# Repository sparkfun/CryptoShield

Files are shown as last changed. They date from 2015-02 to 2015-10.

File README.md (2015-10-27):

SparkFun CryptoShield
=====================

SparkFun CryptoShield

[*SparkFun CryptoShield (DEV-13183)*](https://www.sparkfun.com/products/13183)

Repository Contents
-------------------

* **/Hardware** - Eagle design files (.brd, .sch)
* **/Production** - Production panel files (.brd)

Documentation
--------------

* **[Hookup Guide](https://learn.sparkfun.com/tutorials/crypto-shield-hookup-guide)** - Basic hookup guide for the CryptoShield.
* **[SparkFun Fritzing repo](https://github.com/sparkfun/Fritzing_Parts)** - Fritzing diagrams for SparkFun products.
* **[SparkFun 3D Model repo](https://github.com/sparkfun/3D_Models)** - 3D models of SparkFun products. 

License Information
-------------------

This product is _**open source**_! 

Please review the LICENSE.md file for license information. 

If you have any questions or concerns on licensing, please contact techsupport@sparkfun.com.

Distributed as-is; no warranty is given.

- Your friends at SparkFun.

_A portion of each sale is given back to Josth Datko for continued development of new and exciting Cryptographic tools._

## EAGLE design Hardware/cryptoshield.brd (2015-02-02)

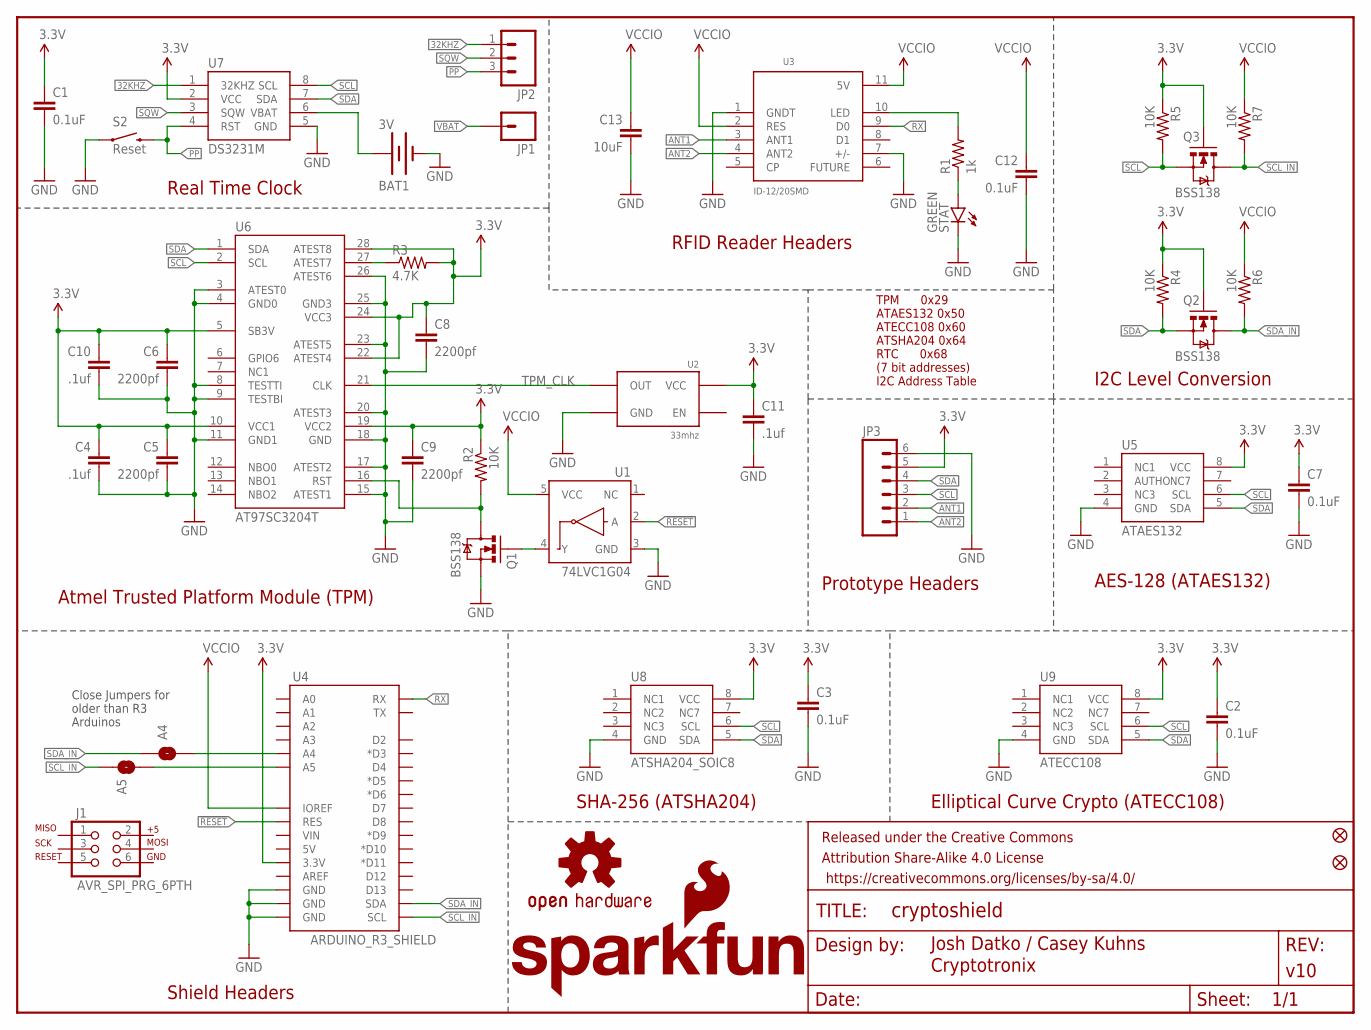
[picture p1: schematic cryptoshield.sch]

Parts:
A4, A5: JUMPER-PAD-2-NOYES_SILK; PAD-JUMPER-2-NO_YES_SILK
BAT1: 3V; BATTCON_12MM
C1, C2, C3, C7, C12: 0.1uF; 0603-CAP
C4, C10, C11: .1uf; 0603-CAP
C5, C6, C8, C9: 2200pf; 0603-CAP
C13: 10uF; 1210
FID1, FID2: FIDUCIAL1X2; FIDUCIAL-1X2
FRAME2: FRAME-LETTER; CREATIVE_COMMONS
J1: AVR_SPI_PRG_6PTH; 2X3
JP1: M01PTH; 1X01
JP2: M03PTH; 1X03
JP3: M06NO_SILK_FEMALE_PTH; 1X06_NO_SILK
LOGO2: OSHW-LOGOS; OSHW-LOGO-S
LOGO3: SFE_LOGO_NAME_FLAME.1_INCH; SFE_LOGO_NAME_FLAME_.1
Q1, Q2, Q3: BSS138; SOT23-3
R1: 1k; 0603-RES
R2, R4, R5, R6, R7: 10K; 0603-RES
R3: 4.7K; 0603
S2: Reset; TACTILE-SWITCH-SMD
STAT: GREEN; LED-0603
U1: 74LVC1G04; SOT353
U2: 33mhz; CRYSTAL-OSC-SMD-5X3.2
U3: ID-12/20SMD; ID-12_SMD
U4: ARDUINO_R3_SHIELD; UNO_R3_SHIELD
U5: ATAES132; SOIC8
U6: AT97SC3204T; TSSOP28
U7: DS3231M; SOIC8
U8: ATSHA204_SOIC8; SOIC8
U9: ATECC108; SOIC8

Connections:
3.3V: C1.1, C2.1, C3.1, C4.1, C5.1, C6.1, C7.1, C8.1, C9.1, C10.1, C11.1, JP3.5, Q2.1 (G), Q3.1 (G), R2.1, R3.2, R4.1, R5.1, U2.4 (VCC), U4.3.3V, U5.8 (VCC), U6.5 (SB3V), U6.10 (VCC1), U6.19 (VCC2), U6.22 (ATEST4), U6.24 (VCC3), U6.28 (ATEST8), U7.2 (VCC), U8.8 (VCC), U9.8 (VCC)
32KHZ: JP2.1, U7.1 (32KHZ)
!RESET: U1.2 (A), U4.RES
ANT1: JP3.2, U3.3 (ANT1)
ANT2: JP3.1, U3.4 (ANT2)
GND: BAT1.GND (-), C1.2, C2.2, C3.2, C4.2, C5.2, C6.2, C7.2, C8.2, C9.2, C10.2, C11.2, C12.2, C13.2, JP3.6, Q1.2 (S), S2.1, STAT.C, U1.3 (GND), U2.2 (GND), U3.1 (GNDT), U3.7 (+/-), U4.GND@0 (GND), U4.GND@1 (GND), U4.GND@2 (GND), U5.4 (GND), U6.3 (ATEST0), U6.4 (GND0), U6.8 (TESTTI), U6.9 (TESTBI), U6.11 (GND1), U6.15 (ATEST1), U6.17 (ATEST2), U6.18 (GND), U6.20 (ATEST3), U6.23 (ATEST5), U6.25 (GND3), U6.26 (ATEST6), U7.5 (GND), U8.4 (GND), U9.4 (GND)
unnamed: R1.2, U3.10 (LED)
unnamed: A4.2, U4.A4
unnamed: A5.2, U4.A5
unnamed: R1.1, STAT.A
unnamed: Q1.3 (D), R2.2, U6.16 (RST)
unnamed: R3.1, U6.27 (ATEST7)
unnamed: Q1.1 (G), U1.4 (Y)
PP: JP2.3, S2.3 (2), U7.4 (RST)
RX: U3.9 (D0), U4.RX
SCL: JP3.3, Q3.2 (S), R5.2, U5.6 (SCL), U6.2 (SCL), U7.8 (SCL), U8.6 (SCL), U9.6 (SCL)
SCL_IN: A5.1, Q3.3 (D), R7.2, U4.SCL
SDA: JP3.4, Q2.2 (S), R4.2, U5.5 (SDA), U6.1 (SDA), U7.7 (SDA), U8.5 (SDA), U9.5 (SDA)
SDA_IN: A4.1, Q2.3 (D), R6.2, U4.SDA
SQW: JP2.2, U7.3 (SQW)
TPM_CLK: U2.3 (OUT), U6.21 (CLK)
VBAT: BAT1.PWR@1 (+), JP1.1, U7.6 (VBAT)
VCCIO: C12.1, C13.1, R6.1, R7.1, U1.5 (VCC), U3.2 (RES), U3.11 (5V), U4.IOREF

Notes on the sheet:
Cryptotronix
RFID Reader Headers
I2C Level Conversion
Real Time Clock
Atmel Trusted Platform Module (TPM)
Elliptical Curve Crypto (ATECC108)
SHA-256 (ATSHA204)
Prototype Headers
I2C Address Table
TPM 0x29 ATAES132 0x50 ATECC108 0x60 ATSHA204 0x64 RTC 0x68 (7 bit addresses)
AES-128 (ATAES132)
Shield Headers
Close Jumpers for older than R3 Arduinos

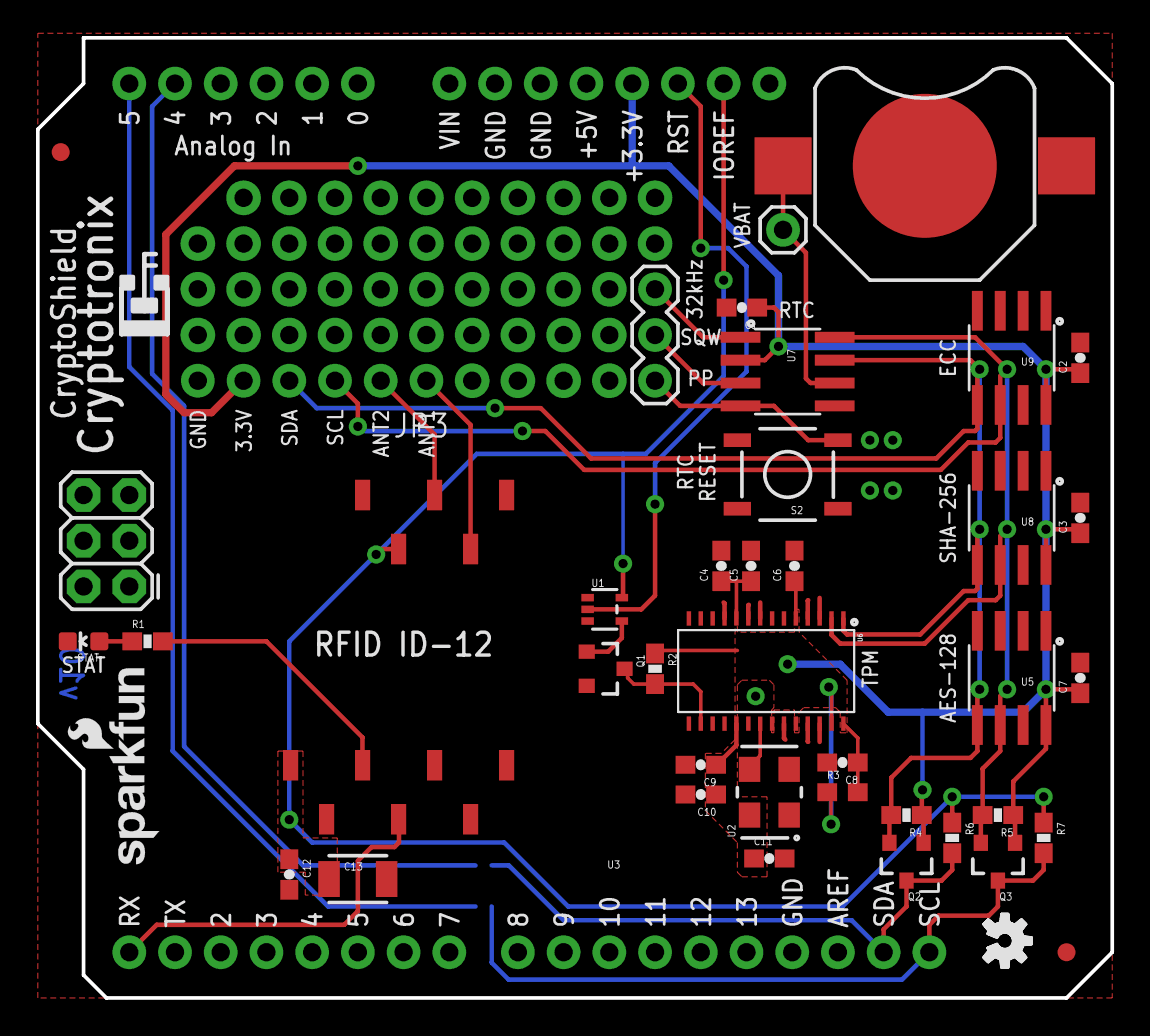
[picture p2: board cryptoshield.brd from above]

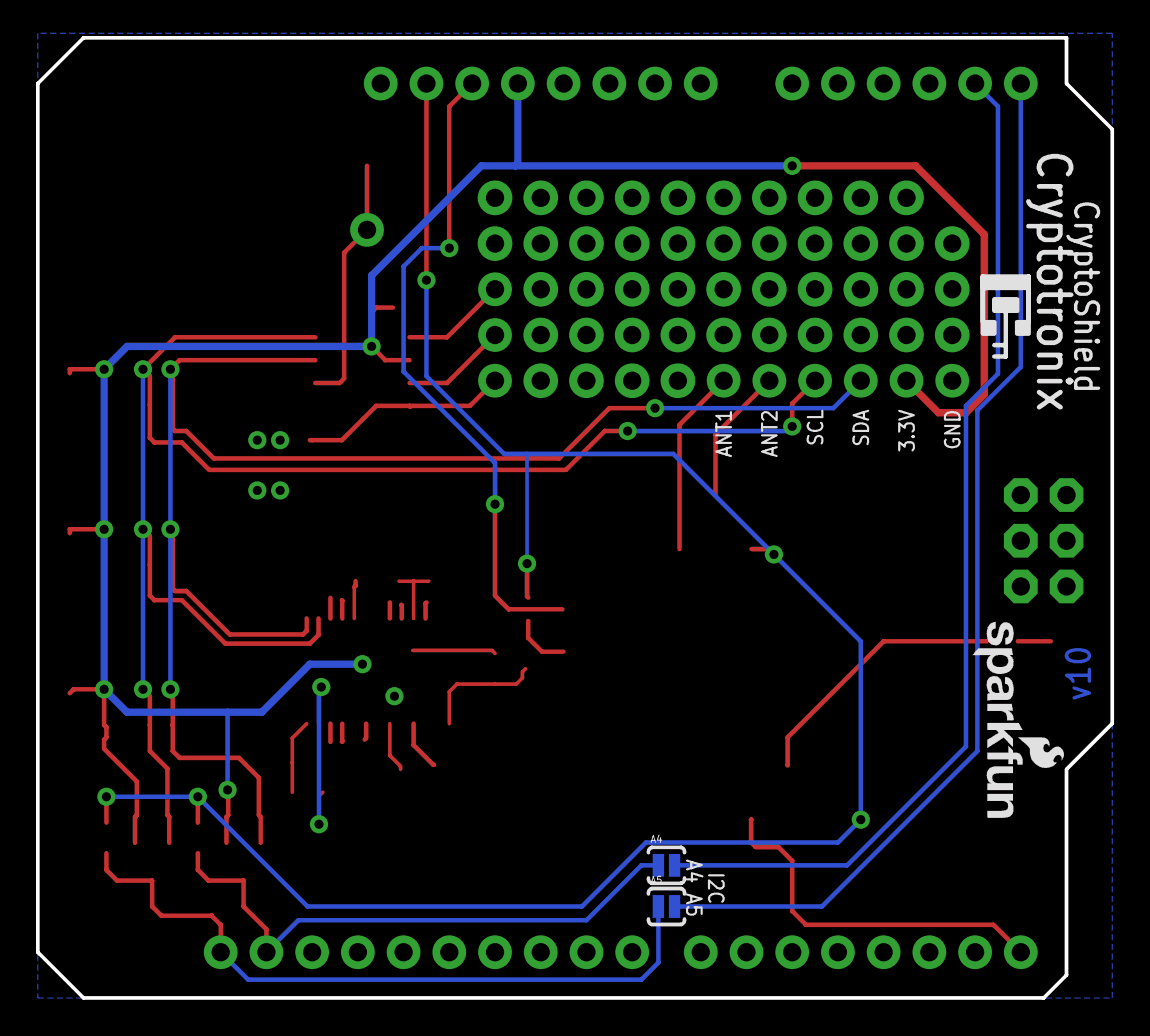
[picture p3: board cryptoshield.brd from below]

Board: 2 copper layers, 59.7 x 53.3 mm, 48 parts (3 on the bottom side), 23 nets.

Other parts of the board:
U$3: OSHW-LOGO-S
U$101: SFE_LOGO_NAME_FLAME_.1

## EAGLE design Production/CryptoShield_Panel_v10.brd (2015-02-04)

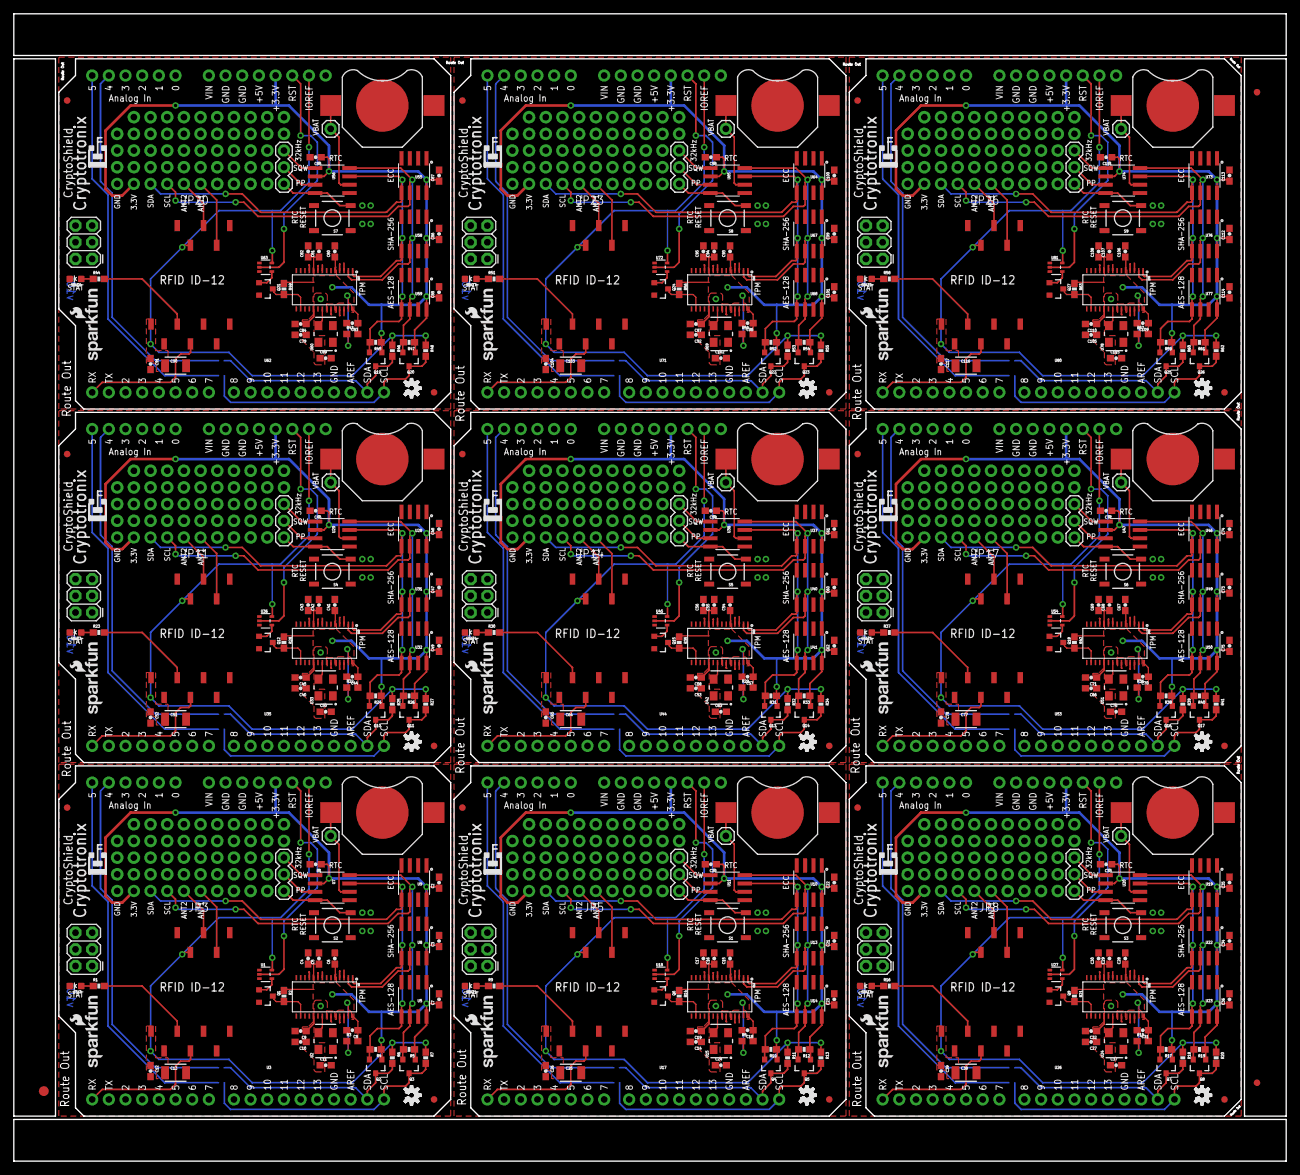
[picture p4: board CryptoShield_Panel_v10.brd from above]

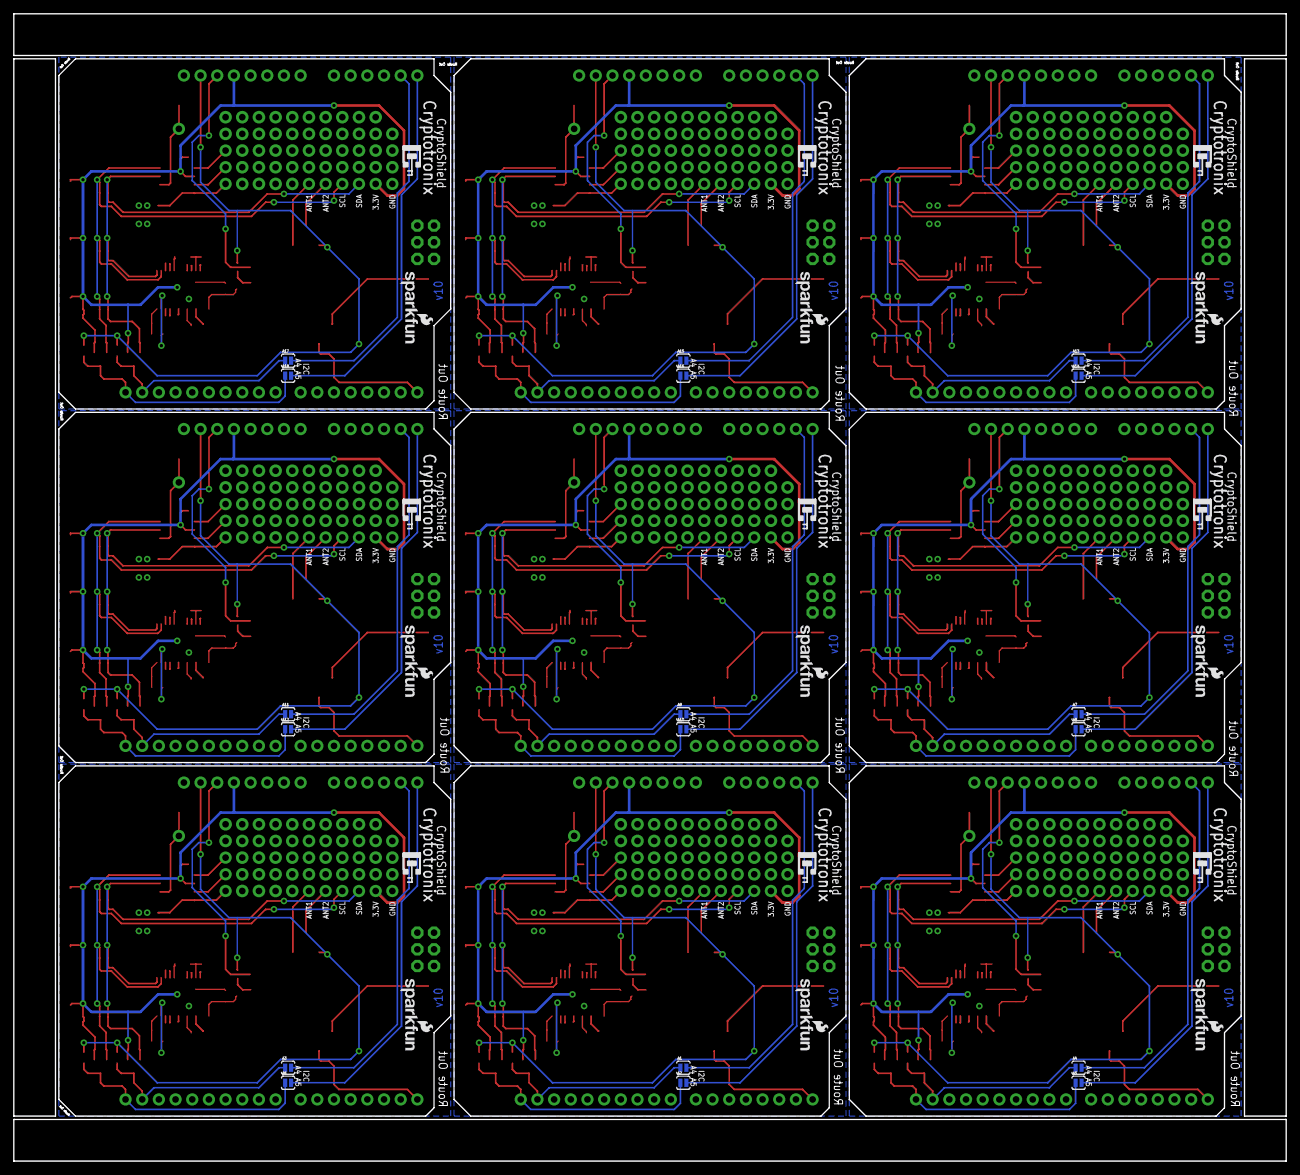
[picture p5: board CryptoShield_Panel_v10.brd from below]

Board: 2 copper layers, 193.8 x 174.8 mm, 426 parts (27 on the bottom side), 207 nets.

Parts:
A1, A2, A3, A4, A5, A6, A7, A8, A9, A10, A11, A12, A13, A14, A15, A16, A17, A18: PAD-JUMPER-2-NO_YES_SILK
BAT1, BAT2, BAT3, BAT4, BAT5, BAT6, BAT7, BAT8, BAT9: 3V; BATTCON_12MM
C1, C2, C3, C7, C12, C20, C21, C22, C23, C26, C33, C34, C35, C36, C39, C46, C47, C48, C49, C52, C59, C60, C61, C62, C65, C72, C73, C74, C75, C78, C85, C86, C87, C88, C91, C98, C99, C100, C101, C104, C111, C112, C113, C114, C117: 0.1uF; 0603-CAP
C4, C10, C11, C14, C17, C24, C27, C30, C37, C40, C43, C50, C53, C56, C63, C66, C69, C76, C79, C82, C89, C92, C95, C102, C105, C108, C115: .1uf; 0603-CAP
C5, C6, C8, C9, C15, C16, C18, C19, C28, C29, C31, C32, C41, C42, C44, C45, C54, C55, C57, C58, C67, C68, C70, C71, C80, C81, C83, C84, C93, C94, C96, C97, C106, C107, C109, C110: 2200pf; 0603-CAP
C13, C25, C38, C51, C64, C77, C90, C103, C116: 10uF; 1210
E$1: FIDUCIAL-1.5X3
E$6, E$8: FIDUCIAL-1X2
FID1, FID2, FID3, FID4, FID5, FID6, FID7, FID8, FID9, FID10, FID11, FID12, FID13, FID14, FID15, FID16, FID17, FID18: FIDUCIAL1X2; FIDUCIAL-1X2
J1, J2, J3, J4, J5, J6, J7, J8, J9: AVR_SPI_PRG_6PTH; 2X3
JP1, JP4, JP7, JP10, JP13, JP16, JP19, JP22, JP25: M01PTH; 1X01
JP2, JP6, JP9, JP12, JP15, JP18, JP21, JP24, JP27: 1X03
JP3, JP5, JP8, JP11, JP14, JP17, JP20, JP23, JP26: 1X06_NO_SILK
LOGO1, LOGO2, LOGO5, LOGO7, LOGO9, LOGO11, LOGO13, LOGO15, LOGO17: OSHW-LOGOS; OSHW-LOGO-S
LOGO3, LOGO4, LOGO6, LOGO8, LOGO10, LOGO12, LOGO14, LOGO16, LOGO18: SFE_LOGO_NAME_FLAME.1_INCH; SFE_LOGO_NAME_FLAME_.1
Q1, Q2, Q3, Q4, Q5, Q6, Q7, Q8, Q9, Q10, Q11, Q12, Q13, Q14, Q15, Q16, Q17, Q18, Q19, Q20, Q21, Q22, Q23, Q24, Q25, Q26, Q27: BSS138; SOT23-3
R1, R9, R16, R23, R30, R37, R44, R51, R58: 1k; 0603-RES
R2, R4, R5, R6, R7, R10, R11, R12, R13, R14, R17, R18, R19, R20, R21, R24, R25, R26, R27, R28, R31, R32, R33, R34, R35, R38, R39, R40, R41, R42, R45, R46, R47, R48, R49, R52, R53, R54, R55, R56, R59, R60, R61, R62, R63: 10K; 0603-RES
R3, R8, R15, R22, R29, R36, R43, R50, R57: 4.7K; 0603
S1, S2, S3, S4, S5, S6, S7, S8, S9: Reset; TACTILE-SWITCH-SMD
STAT, STAT1, STAT2, STAT3, STAT4, STAT5, STAT6, STAT7, STAT8: GREEN; LED-0603
U1, U18, U27, U36, U45, U54, U63, U72, U81: 74LVC1G04; SOT353
U2, U15, U24, U33, U42, U51, U60, U69, U78: 33mhz; CRYSTAL-OSC-SMD-5X3.2
U3, U17, U26, U35, U44, U53, U62, U71, U80: ID-12/20SMD; ID-12_SMD
U4, U16, U25, U34, U43, U52, U61, U70, U79: ARDUINO_R3_SHIELD; UNO_R3_SHIELD
U5, U14, U23, U32, U41, U50, U59, U68, U77: ATAES132; SOIC8
U6, U12, U21, U30, U39, U48, U57, U66, U75: AT97SC3204T; TSSOP28
U7, U11, U20, U29, U38, U47, U56, U65, U74: DS3231M; SOIC8
U8, U13, U22, U31, U40, U49, U58, U67, U76: ATSHA204_SOIC8; SOIC8
U9, U10, U19, U28, U37, U46, U55, U64, U73: ATECC108; SOIC8
U$1, U$3, U$4, U$6, U$8, U$10, U$12, U$14, U$16: OSHW-LOGO-S
U$2, U$5, U$7, U$9, U$11, U$13, U$15, U$17, U$101: SFE_LOGO_NAME_FLAME_.1

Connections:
3.3V: C1.1, C2.1, C3.1, C4.1, C5.1, C6.1, C7.1, C8.1, C9.1, C10.1, C11.1, JP3.5, Q2.1, Q3.1, R2.1, R3.2, R4.1, R5.1, U2.4, U4.3.3V, U5.8, U6.5, U6.10, U6.19, U6.22, U6.24, U6.28, U7.2, U8.8, U9.8
3.3V1: C14.1, C15.1, C16.1, C17.1, C18.1, C19.1, C20.1, C21.1, C22.1, C23.1, C24.1, JP5.5, Q4.1, Q5.1, R8.2, R10.1, R12.1, R14.1, U10.8, U11.2, U12.5, U12.10, U12.19, U12.22, U12.24, U12.28, U13.8, U14.8, U15.4, U16.3.3V
3.3V2: C27.1, C28.1, C29.1, C30.1, C31.1, C32.1, C33.1, C34.1, C35.1, C36.1, C37.1, JP8.5, Q7.1, Q8.1, R15.2, R17.1, R19.1, R21.1, U19.8, U20.2, U21.5, U21.10, U21.19, U21.22, U21.24, U21.28, U22.8, U23.8, U24.4, U25.3.3V
3.3V3: C40.1, C41.1, C42.1, C43.1, C44.1, C45.1, C46.1, C47.1, C48.1, C49.1, C50.1, JP11.5, Q10.1, Q11.1, R22.2, R24.1, R26.1, R28.1, U28.8, U29.2, U30.5, U30.10, U30.19, U30.22, U30.24, U30.28, U31.8, U32.8, U33.4, U34.3.3V
3.3V4: C53.1, C54.1, C55.1, C56.1, C57.1, C58.1, C59.1, C60.1, C61.1, C62.1, C63.1, JP14.5, Q13.1, Q14.1, R29.2, R31.1, R33.1, R35.1, U37.8, U38.2, U39.5, U39.10, U39.19, U39.22, U39.24, U39.28, U40.8, U41.8, U42.4, U43.3.3V
3.3V5: C66.1, C67.1, C68.1, C69.1, C70.1, C71.1, C72.1, C73.1, C74.1, C75.1, C76.1, JP17.5, Q16.1, Q17.1, R36.2, R38.1, R40.1, R42.1, U46.8, U47.2, U48.5, U48.10, U48.19, U48.22, U48.24, U48.28, U49.8, U50.8, U51.4, U52.3.3V
3.3V6: C79.1, C80.1, C81.1, C82.1, C83.1, C84.1, C85.1, C86.1, C87.1, C88.1, C89.1, JP20.5, Q19.1, Q20.1, R43.2, R45.1, R47.1, R49.1, U55.8, U56.2, U57.5, U57.10, U57.19, U57.22, U57.24, U57.28, U58.8, U59.8, U60.4, U61.3.3V
3.3V7: C92.1, C93.1, C94.1, C95.1, C96.1, C97.1, C98.1, C99.1, C100.1, C101.1, C102.1, JP23.5, Q22.1, Q23.1, R50.2, R52.1, R54.1, R56.1, U64.8, U65.2, U66.5, U66.10, U66.19, U66.22, U66.24, U66.28, U67.8, U68.8, U69.4, U70.3.3V
3.3V8: C105.1, C106.1, C107.1, C108.1, C109.1, C110.1, C111.1, C112.1, C113.1, C114.1, C115.1, JP26.5, Q25.1, Q26.1, R57.2, R59.1, R61.1, R63.1, U73.8, U74.2, U75.5, U75.10, U75.19, U75.22, U75.24, U75.28, U76.8, U77.8, U78.4, U79.3.3V
32KHZ: JP2.1, U7.1
32KHZ1: JP6.1, U11.1
32KHZ2: JP9.1, U20.1
32KHZ3: JP12.1, U29.1
32KHZ4: JP15.1, U38.1
32KHZ5: JP18.1, U47.1
32KHZ6: JP21.1, U56.1
32KHZ7: JP24.1, U65.1
32KHZ8: JP27.1, U74.1
!RESET: U1.2, U4.RES
!RESET1: U16.RES, U18.2
!RESET2: U25.RES, U27.2
!RESET3: U34.RES, U36.2
!RESET4: U43.RES, U45.2
!RESET5: U52.RES, U54.2
!RESET6: U61.RES, U63.2
!RESET7: U70.RES, U72.2
!RESET8: U79.RES, U81.2
ANT1: JP3.2, U3.3
ANT2: JP3.1, U3.4
ANT3: JP5.2, U17.3
ANT4: JP5.1, U17.4
ANT5: JP8.2, U26.3
ANT6: JP8.1, U26.4
ANT7: JP11.2, U35.3
ANT8: JP11.1, U35.4
ANT9: JP14.2, U44.3
ANT10: JP14.1, U44.4
ANT11: JP17.2, U53.3
ANT12: JP17.1, U53.4
ANT13: JP20.2, U62.3
ANT14: JP20.1, U62.4
ANT15: JP23.2, U71.3
ANT16: JP23.1, U71.4
ANT17: JP26.2, U80.3
ANT18: JP26.1, U80.4
GND: BAT1.GND, C1.2, C2.2, C3.2, C4.2, C5.2, C6.2, C7.2, C8.2, C9.2, C10.2, C11.2, C12.2, C13.2, JP3.6, Q1.2, S2.1, STAT.C, U1.3, U2.2, U3.1, U3.7, U4.GND@0, U4.GND@1, U4.GND@2, U5.4, U6.3, U6.4, U6.8, U6.9, U6.11, U6.15, U6.17, U6.18, U6.20, U6.23, U6.25, U6.26, U7.5, U8.4, U9.4
GND1: BAT2.GND, C14.2, C15.2, C16.2, C17.2, C18.2, C19.2, C20.2, C21.2, C22.2, C23.2, C24.2, C25.2, C26.2, JP5.6, Q6.2, S1.1, STAT1.C, U10.4, U11.5, U12.3, U12.4, U12.8, U12.9, U12.11, U12.15, U12.17, U12.18, U12.20, U12.23, U12.25, U12.26, U13.4, U14.4, U15.2, U16.GND@0, U16.GND@1, U16.GND@2, U17.1, U17.7, U18.3
GND2: BAT3.GND, C27.2, C28.2, C29.2, C30.2, C31.2, C32.2, C33.2, C34.2, C35.2, C36.2, C37.2, C38.2, C39.2, JP8.6, Q9.2, S3.1, STAT2.C, U19.4, U20.5, U21.3, U21.4, U21.8, U21.9, U21.11, U21.15, U21.17, U21.18, U21.20, U21.23, U21.25, U21.26, U22.4, U23.4, U24.2, U25.GND@0, U25.GND@1, U25.GND@2, U26.1, U26.7, U27.3
GND3: BAT4.GND, C40.2, C41.2, C42.2, C43.2, C44.2, C45.2, C46.2, C47.2, C48.2, C49.2, C50.2, C51.2, C52.2, JP11.6, Q12.2, S4.1, STAT3.C, U28.4, U29.5, U30.3, U30.4, U30.8, U30.9, U30.11, U30.15, U30.17, U30.18, U30.20, U30.23, U30.25, U30.26, U31.4, U32.4, U33.2, U34.GND@0, U34.GND@1, U34.GND@2, U35.1, U35.7, U36.3
GND4: BAT5.GND, C53.2, C54.2, C55.2, C56.2, C57.2, C58.2, C59.2, C60.2, C61.2, C62.2, C63.2, C64.2, C65.2, JP14.6, Q15.2, S5.1, STAT4.C, U37.4, U38.5, U39.3, U39.4, U39.8, U39.9, U39.11, U39.15, U39.17, U39.18, U39.20, U39.23, U39.25, U39.26, U40.4, U41.4, U42.2, U43.GND@0, U43.GND@1, U43.GND@2, U44.1, U44.7, U45.3
GND5: BAT6.GND, C66.2, C67.2, C68.2, C69.2, C70.2, C71.2, C72.2, C73.2, C74.2, C75.2, C76.2, C77.2, C78.2, JP17.6, Q18.2, S6.1, STAT5.C, U46.4, U47.5, U48.3, U48.4, U48.8, U48.9, U48.11, U48.15, U48.17, U48.18, U48.20, U48.23, U48.25, U48.26, U49.4, U50.4, U51.2, U52.GND@0, U52.GND@1, U52.GND@2, U53.1, U53.7, U54.3
GND6: BAT7.GND, C79.2, C80.2, C81.2, C82.2, C83.2, C84.2, C85.2, C86.2, C87.2, C88.2, C89.2, C90.2, C91.2, JP20.6, Q21.2, S7.1, STAT6.C, U55.4, U56.5, U57.3, U57.4, U57.8, U57.9, U57.11, U57.15, U57.17, U57.18, U57.20, U57.23, U57.25, U57.26, U58.4, U59.4, U60.2, U61.GND@0, U61.GND@1, U61.GND@2, U62.1, U62.7, U63.3
GND7: BAT8.GND, C92.2, C93.2, C94.2, C95.2, C96.2, C97.2, C98.2, C99.2, C100.2, C101.2, C102.2, C103.2, C104.2, JP23.6, Q24.2, S8.1, STAT7.C, U64.4, U65.5, U66.3, U66.4, U66.8, U66.9, U66.11, U66.15, U66.17, U66.18, U66.20, U66.23, U66.25, U66.26, U67.4, U68.4, U69.2, U70.GND@0, U70.GND@1, U70.GND@2, U71.1, U71.7, U72.3
GND8: BAT9.GND, C105.2, C106.2, C107.2, C108.2, C109.2, C110.2, C111.2, C112.2, C113.2, C114.2, C115.2, C116.2, C117.2, JP26.6, Q27.2, S9.1, STAT8.C, U73.4, U74.5, U75.3, U75.4, U75.8, U75.9, U75.11, U75.15, U75.17, U75.18, U75.20, U75.23, U75.25, U75.26, U76.4, U77.4, U78.2, U79.GND@0, U79.GND@1, U79.GND@2, U80.1, U80.7, U81.3
unnamed: R1.2, U3.10
unnamed: A4.2, U4.A4
unnamed: A5.2, U4.A5
unnamed: R1.1, STAT.A
unnamed: Q1.3, R2.2, U6.16
unnamed: R3.1, U6.27
unnamed: Q1.1, U1.4
unnamed: R8.1, U12.27
unnamed: R9.1, STAT1.A
unnamed: R9.2, U17.10
unnamed: A1.2, U16.A4
unnamed: A2.2, U16.A5
unnamed: Q6.3, R14.2, U12.16
unnamed: Q6.1, U18.4
unnamed: R15.1, U21.27
unnamed: R16.1, STAT2.A
unnamed: R16.2, U26.10
unnamed: A3.2, U25.A4
unnamed: A6.2, U25.A5
unnamed: Q9.3, R21.2, U21.16
unnamed: Q9.1, U27.4
unnamed: R22.1, U30.27
unnamed: R23.1, STAT3.A
unnamed: R23.2, U35.10
unnamed: A7.2, U34.A4
unnamed: A8.2, U34.A5
unnamed: Q12.3, R28.2, U30.16
unnamed: Q12.1, U36.4
unnamed: R29.1, U39.27
unnamed: R30.1, STAT4.A
unnamed: R30.2, U44.10
unnamed: A9.2, U43.A4
unnamed: A10.2, U43.A5
unnamed: Q15.3, R35.2, U39.16
unnamed: Q15.1, U45.4
unnamed: R36.1, U48.27
unnamed: R37.1, STAT5.A
unnamed: R37.2, U53.10
unnamed: A11.2, U52.A4
unnamed: A12.2, U52.A5
unnamed: Q18.3, R42.2, U48.16
unnamed: Q18.1, U54.4
unnamed: R43.1, U57.27
unnamed: R44.1, STAT6.A
unnamed: R44.2, U62.10
unnamed: A13.2, U61.A4
unnamed: A14.2, U61.A5
unnamed: Q21.3, R49.2, U57.16
unnamed: Q21.1, U63.4
unnamed: R50.1, U66.27
unnamed: R51.1, STAT7.A
unnamed: R51.2, U71.10
unnamed: A15.2, U70.A4
unnamed: A16.2, U70.A5
unnamed: Q24.3, R56.2, U66.16
unnamed: Q24.1, U72.4
unnamed: R57.1, U75.27
unnamed: R58.1, STAT8.A
unnamed: R58.2, U80.10
unnamed: A17.2, U79.A4
unnamed: A18.2, U79.A5
unnamed: Q27.3, R63.2, U75.16
unnamed: Q27.1, U81.4
PP: JP2.3, S2.3, U7.4
PP1: JP6.3, S1.3, U11.4
PP2: JP9.3, S3.3, U20.4
PP3: JP12.3, S4.3, U29.4
PP4: JP15.3, S5.3, U38.4
PP5: JP18.3, S6.3, U47.4
PP6: JP21.3, S7.3, U56.4
PP7: JP24.3, S8.3, U65.4
PP8: JP27.3, S9.3, U74.4
RX: U3.9, U4.RX
RX1: U16.RX, U17.9
RX2: U25.RX, U26.9
RX3: U34.RX, U35.9
RX4: U43.RX, U44.9
RX5: U52.RX, U53.9
RX6: U61.RX, U62.9
RX7: U70.RX, U71.9
RX8: U79.RX, U80.9
SCL: JP3.3, Q3.2, R5.2, U5.6, U6.2, U7.8, U8.6, U9.6
SCL1: JP5.3, Q5.2, R12.2, U10.6, U11.8, U12.2, U13.6, U14.6
SCL2: JP8.3, Q8.2, R19.2, U19.6, U20.8, U21.2, U22.6, U23.6
SCL3: JP11.3, Q11.2, R26.2, U28.6, U29.8, U30.2, U31.6, U32.6
SCL4: JP14.3, Q14.2, R33.2, U37.6, U38.8, U39.2, U40.6, U41.6
SCL5: JP17.3, Q17.2, R40.2, U46.6, U47.8, U48.2, U49.6, U50.6
SCL6: JP20.3, Q20.2, R47.2, U55.6, U56.8, U57.2, U58.6, U59.6
SCL7: JP23.3, Q23.2, R54.2, U64.6, U65.8, U66.2, U67.6, U68.6
SCL8: JP26.3, Q26.2, R61.2, U73.6, U74.8, U75.2, U76.6, U77.6
SCL_IN: A5.1, Q3.3, R7.2, U4.SCL
SCL_IN1: A2.1, Q5.3, R13.2, U16.SCL
SCL_IN2: A6.1, Q8.3, R20.2, U25.SCL
SCL_IN3: A8.1, Q11.3, R27.2, U34.SCL
SCL_IN4: A10.1, Q14.3, R34.2, U43.SCL
SCL_IN5: A12.1, Q17.3, R41.2, U52.SCL
SCL_IN6: A14.1, Q20.3, R48.2, U61.SCL
SCL_IN7: A16.1, Q23.3, R55.2, U70.SCL
SCL_IN8: A18.1, Q26.3, R62.2, U79.SCL
SDA: JP3.4, Q2.2, R4.2, U5.5, U6.1, U7.7, U8.5, U9.5
SDA1: JP5.4, Q4.2, R10.2, U10.5, U11.7, U12.1, U13.5, U14.5
SDA2: JP8.4, Q7.2, R17.2, U19.5, U20.7, U21.1, U22.5, U23.5
SDA3: JP11.4, Q10.2, R24.2, U28.5, U29.7, U30.1, U31.5, U32.5
SDA4: JP14.4, Q13.2, R31.2, U37.5, U38.7, U39.1, U40.5, U41.5
SDA5: JP17.4, Q16.2, R38.2, U46.5, U47.7, U48.1, U49.5, U50.5
SDA6: JP20.4, Q19.2, R45.2, U55.5, U56.7, U57.1, U58.5, U59.5
SDA7: JP23.4, Q22.2, R52.2, U64.5, U65.7, U66.1, U67.5, U68.5
SDA8: JP26.4, Q25.2, R59.2, U73.5, U74.7, U75.1, U76.5, U77.5
SDA_IN: A4.1, Q2.3, R6.2, U4.SDA
SDA_IN1: A1.1, Q4.3, R11.2, U16.SDA
SDA_IN2: A3.1, Q7.3, R18.2, U25.SDA
SDA_IN3: A7.1, Q10.3, R25.2, U34.SDA
SDA_IN4: A9.1, Q13.3, R32.2, U43.SDA
SDA_IN5: A11.1, Q16.3, R39.2, U52.SDA
SDA_IN6: A13.1, Q19.3, R46.2, U61.SDA
SDA_IN7: A15.1, Q22.3, R53.2, U70.SDA
SDA_IN8: A17.1, Q25.3, R60.2, U79.SDA
SQW: JP2.2, U7.3
SQW1: JP6.2, U11.3
SQW2: JP9.2, U20.3
SQW3: JP12.2, U29.3
SQW4: JP15.2, U38.3
SQW5: JP18.2, U47.3
SQW6: JP21.2, U56.3
SQW7: JP24.2, U65.3
SQW8: JP27.2, U74.3
TPM_CLK: U2.3, U6.21
TPM_CLK1: U12.21, U15.3
TPM_CLK2: U21.21, U24.3
TPM_CLK3: U30.21, U33.3
TPM_CLK4: U39.21, U42.3
TPM_CLK5: U48.21, U51.3
TPM_CLK6: U57.21, U60.3
TPM_CLK7: U66.21, U69.3
TPM_CLK8: U75.21, U78.3
VBAT: BAT1.PWR@1, JP1.1, U7.6
VBAT1: BAT2.PWR@1, JP4.1, U11.6
VBAT2: BAT3.PWR@1, JP7.1, U20.6
VBAT3: BAT4.PWR@1, JP10.1, U29.6
VBAT4: BAT5.PWR@1, JP13.1, U38.6
VBAT5: BAT6.PWR@1, JP16.1, U47.6
VBAT6: BAT7.PWR@1, JP19.1, U56.6
VBAT7: BAT8.PWR@1, JP22.1, U65.6
VBAT8: BAT9.PWR@1, JP25.1, U74.6
VCCIO: C12.1, C13.1, R6.1, R7.1, U1.5, U3.2, U3.11, U4.IOREF
VCCIO1: C25.1, C26.1, R11.1, R13.1, U16.IOREF, U17.2, U17.11, U18.5
VCCIO2: C38.1, C39.1, R18.1, R20.1, U25.IOREF, U26.2, U26.11, U27.5
VCCIO3: C51.1, C52.1, R25.1, R27.1, U34.IOREF, U35.2, U35.11, U36.5
VCCIO4: C64.1, C65.1, R32.1, R34.1, U43.IOREF, U44.2, U44.11, U45.5
VCCIO5: C77.1, C78.1, R39.1, R41.1, U52.IOREF, U53.2, U53.11, U54.5
VCCIO6: C90.1, C91.1, R46.1, R48.1, U61.IOREF, U62.2, U62.11, U63.5
VCCIO7: C103.1, C104.1, R53.1, R55.1, U70.IOREF, U71.2, U71.11, U72.5
VCCIO8: C116.1, C117.1, R60.1, R62.1, U79.IOREF, U80.2, U80.11, U81.5

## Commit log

2014-10-08 initial commit, Work in progress
    [cryptoshield.brd, cryptoshield.sch]
2014-10-09 more work done, still work in progress
    [cryptoshield.brd, cryptoshield.sch]
2014-10-09 finished layout, ready for review
    [cryptoshield.brd, cryptoshield.sch]
2014-10-15 fixed silk
    [cryptoshield.brd]
2014-10-15 fixed wire
    [cryptoshield.brd]
2014-10-21 fixed silk added gitignore
    [cryptoshield.brd]
2014-10-21 changed name of part
    [cryptoshield.brd, cryptoshield.sch]
2014-11-06 Changes 5V to IOREF
    [cryptoshield.brd, cryptoshield.sch]
2014-12-09 added mosfet reset circuit to couple TPM reset to Arduino Reset pin
    [cryptoshield.brd, cryptoshield.sch]
2015-01-08 made changed to isolate Reset from 5V
    [cryptoshield.brd, cryptoshield.sch]
2015-01-09 modified layout to meet checklist compliance
    [cryptoshield.brd, cryptoshield.sch]
2015-01-12 fixed all github issues
    [cryptoshield.brd, cryptoshield.sch]
2015-01-12 fixed fonts
    [cryptoshield.brd]
2015-02-02 Moved Stat Led away from board re-arranged proto area to conform with I2C standard layout flipped logos to match lable orientation
    [cryptoshield.brd, cryptoshield.sch]
2015-02-04 created panel v10
    [CryptoShield_Panel_v10.brd]
2015-10-27 Updating product repo structure, readme with product info
    [CryptoShield_Panel_v10.brd]

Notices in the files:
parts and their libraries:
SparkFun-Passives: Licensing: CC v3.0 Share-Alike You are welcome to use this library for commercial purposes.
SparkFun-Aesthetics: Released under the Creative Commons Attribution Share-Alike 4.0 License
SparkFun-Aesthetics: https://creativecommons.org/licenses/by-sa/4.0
